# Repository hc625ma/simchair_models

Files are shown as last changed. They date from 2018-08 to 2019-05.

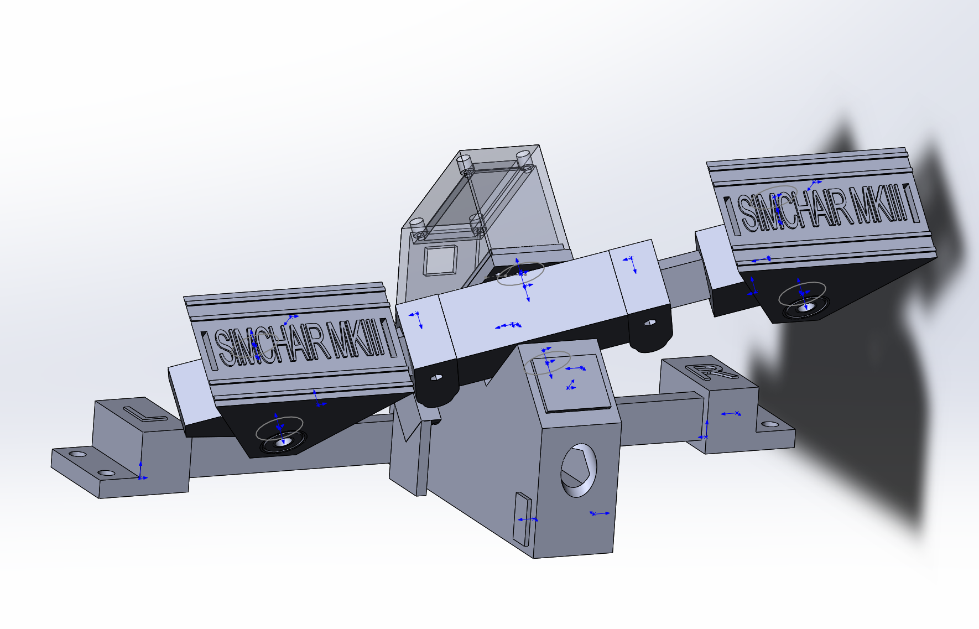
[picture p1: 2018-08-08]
Components/Peripherals/Helicopter pedals/PNG/pedals.png

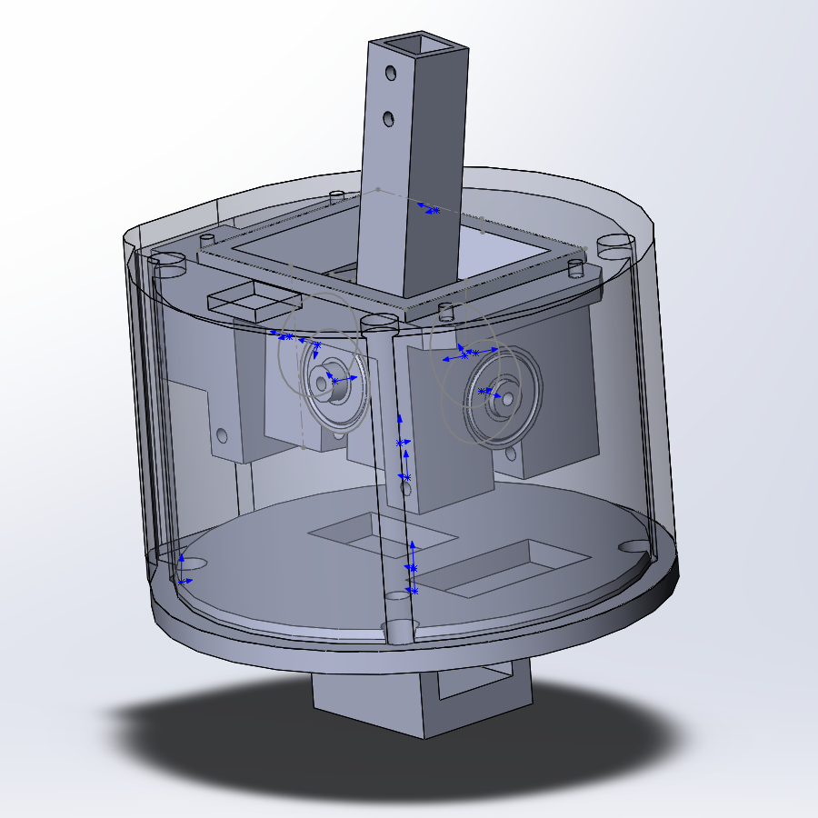
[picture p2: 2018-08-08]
Components/Peripherals/Flight stick gimbal 608zz light/MANUALS/cyclic4.png

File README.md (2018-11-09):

# simchair_models
Simchair MKIII 3D printable models repository

Simchair MKIII

This repo contains all current (supported) models of Simchair MKIII project, sources and oriented STL files. 
All the files are named using this scheme:
peripheral_part_name_partnumber

You can also download all the stuff (and find assembly manuals, BOMs etc) at http://hc625ma.org, the site is auto-synced with models and software repos.

If you have questions, please contact me through comments on the site.

Cheers!

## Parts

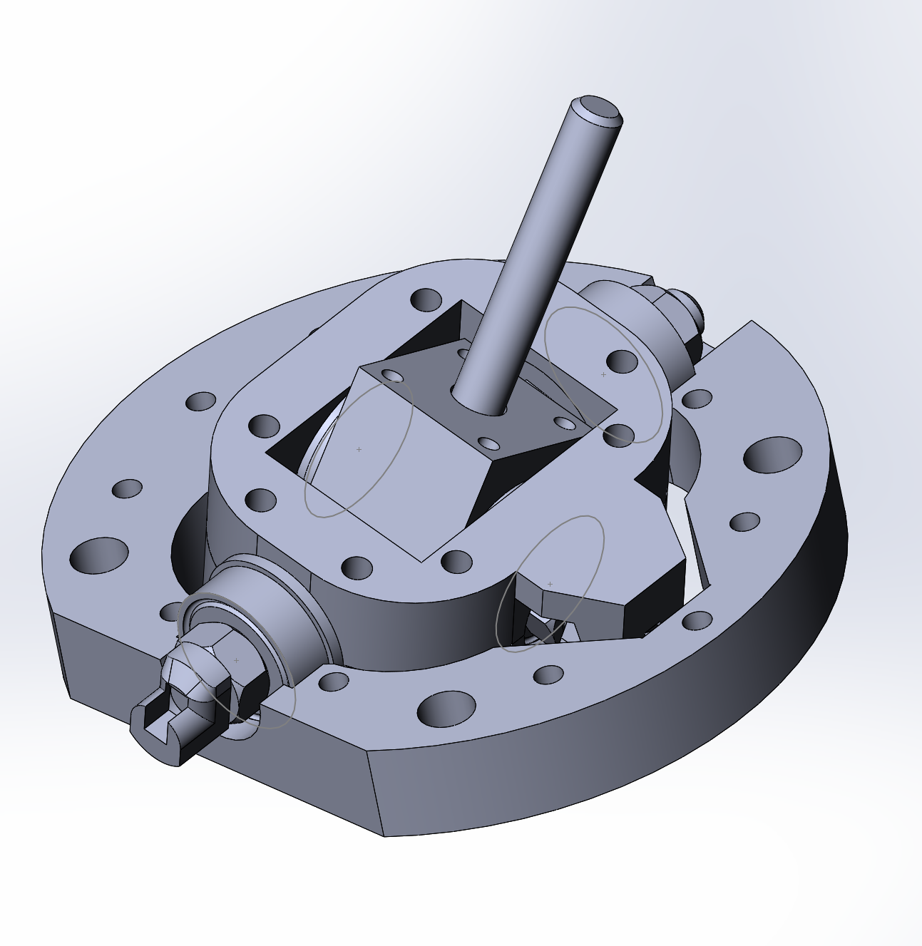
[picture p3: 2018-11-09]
Components/Peripherals/Flight stick gimbal 608zz reinforced/PNG/gimbal06.png

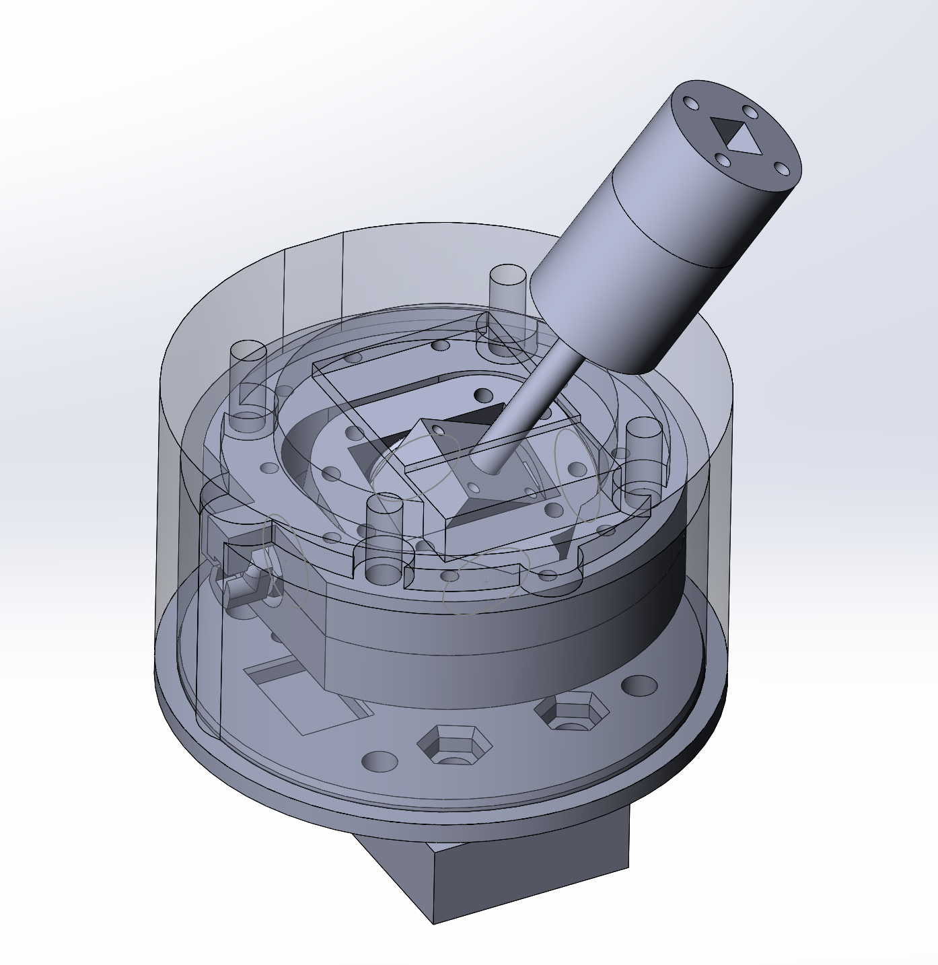
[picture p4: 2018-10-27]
Components/Peripherals/Flight stick gimbal 608zz reinforced/PNG/gimbal01.png

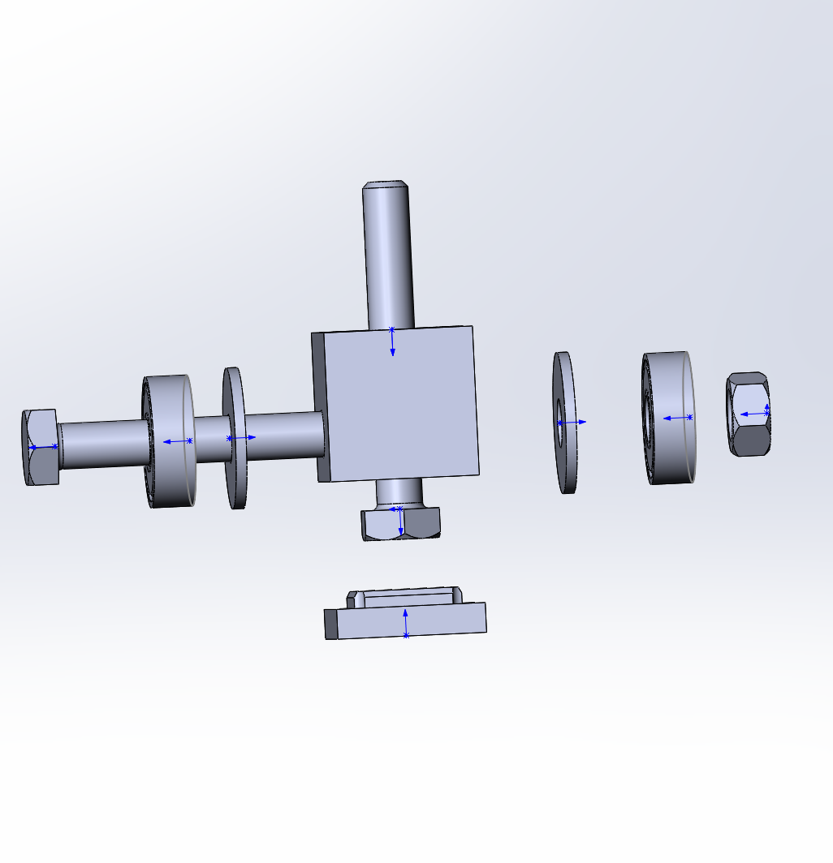
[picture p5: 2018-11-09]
Components/Peripherals/Flight stick gimbal 608zz reinforced/PNG/gimbal02.png

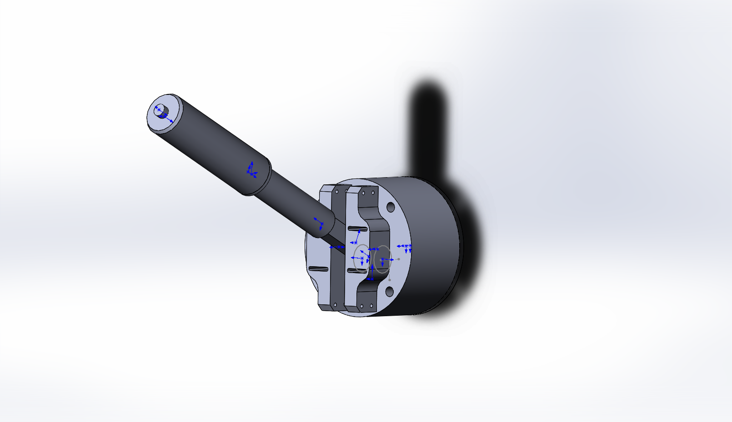
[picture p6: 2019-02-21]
Components/Peripherals/dev/Simple collective/PNG/collective.PNG

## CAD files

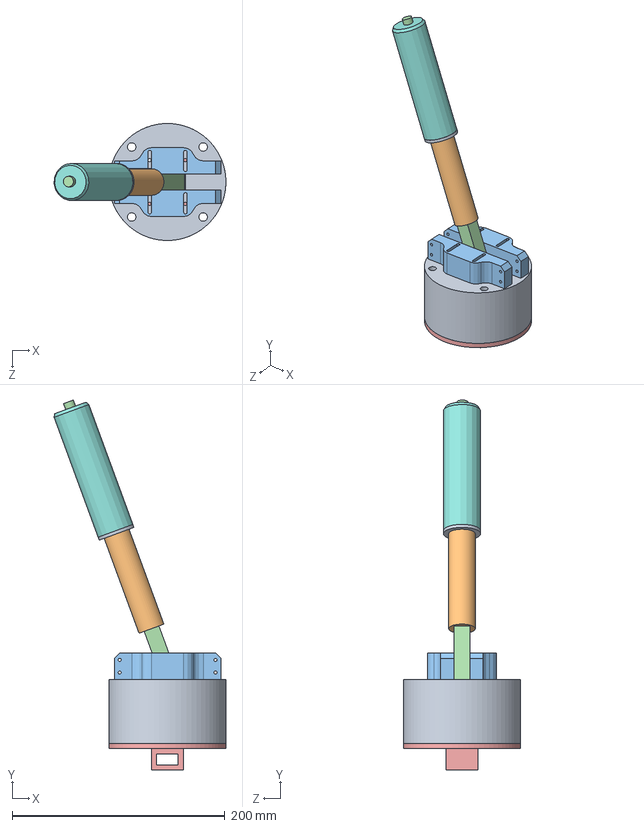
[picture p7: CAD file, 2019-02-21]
Components/Peripherals/dev/Simple collective/SLDPRT/collective.SLDASM
161.5 x 347.7 x 110.0 mm
case_collective
collective_frame_4,5x42mm
608_bearing_v1 x 2
collective_connector
collective_case_bottom_cover
aluminium_square_pipe_10x250
throttle_resistor_mount_v2
throttle
throttle_rear_mount
collective_lever_decorative_cover
tensioner x 2
throttle_handle_wedge

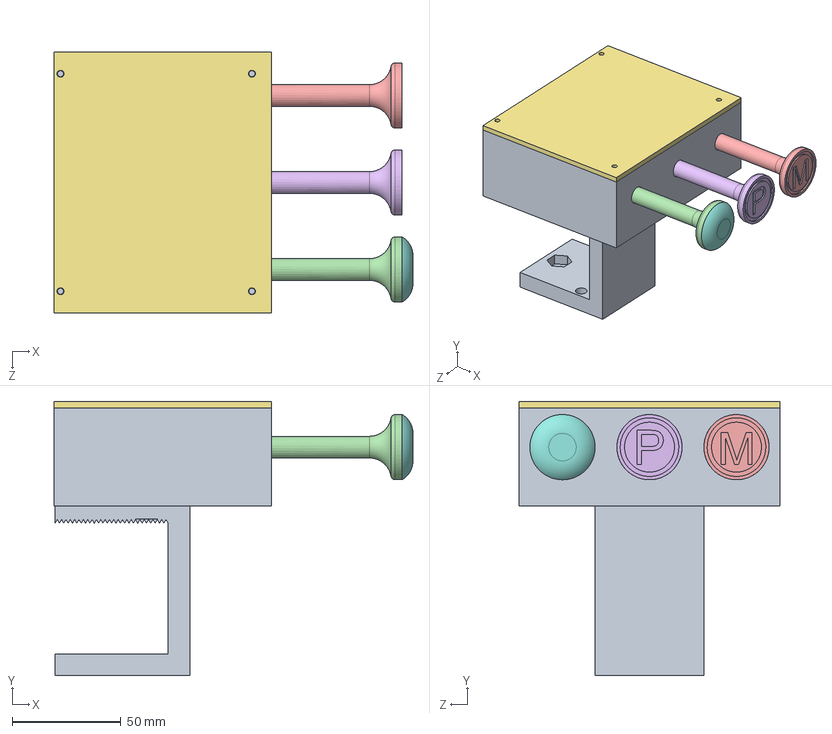
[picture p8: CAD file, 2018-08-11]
Components/Peripherals/Single engine GA controls/SLDPRT/single_eng_ga_controls.SLDASM
165.1 x 126.0 x 120.0 mm
single_eng_ga_controls_enclosure_p1_single_eng_ga_controls01
slider_base x 3
slider x 3
single_eng_ga_controls_throttle_single_eng_ga_controls03
single_eng_ga_controls_mixture_single_eng_ga_controls05
single_eng_ga_controls_prop_single_eng_ga_controls04
single_eng_ga_controls_enclosure_p2_single_eng_ga_controls02
single_eng_ga_controls_knob_cover_single_eng_ga_controls06
single_eng_ga_controls_desk_mount_single_eng_ga_controls07

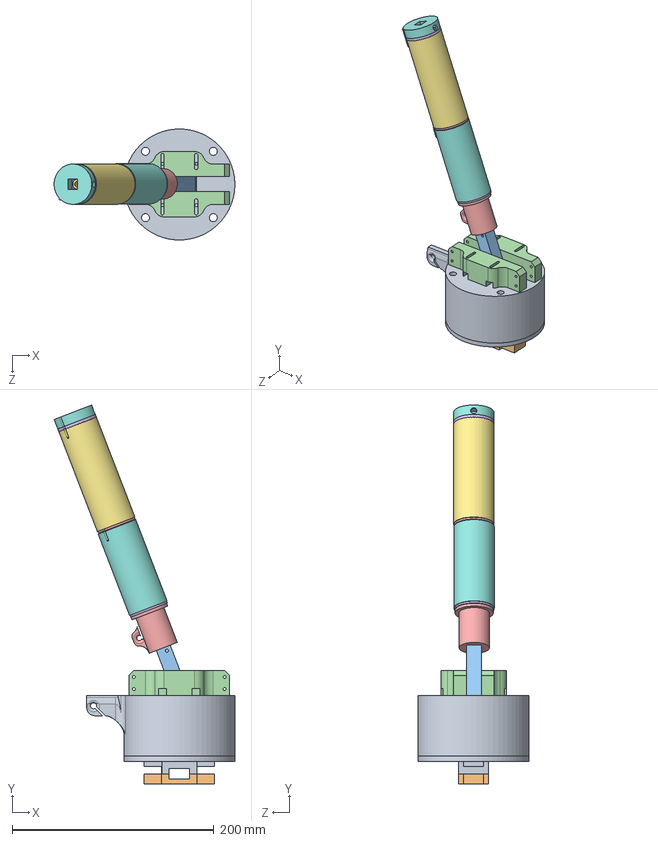
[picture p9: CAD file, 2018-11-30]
Components/Peripherals/Twin collective/SLDPRT/twin_collective.SLDASM
179.1 x 375.5 x 110.0 mm
twin_collective_enclosure_twin_collective01
twin_collective_lever_frame_twin_collective04
608_bearing_v1 x 2
twin_collective_tensioner_twin_collective06 x 2
twin_collective_rubber_bands_holder_twin_collective08
twin_collective_throttle2_frame_p1_twin_collective09
twin_collective_throttle2_frame_p2_twin_collective10
twin_collective_throttle2_grip_twin_collective11
alu_square_pipe_10x10x130
alu_square_pipe_10x10x50
twin_collective_lever_connector_twin_collective05
twin_collective_magnet_holder_6x6x4mm_twin_collective07
twin_collective_throttle1_frame_p1_twin_collective12
twin_collective_throttle1_frame_p2_twin_collective13
twin_collective_throttle1_grip_twin_collective14
twin_collective_head_i2c_connector_housing_twin_collective15
twin_collective_enclosure_bottom_p1_twin_collective02
twin_collective_enclosure_bottom_p2_twin_collective03

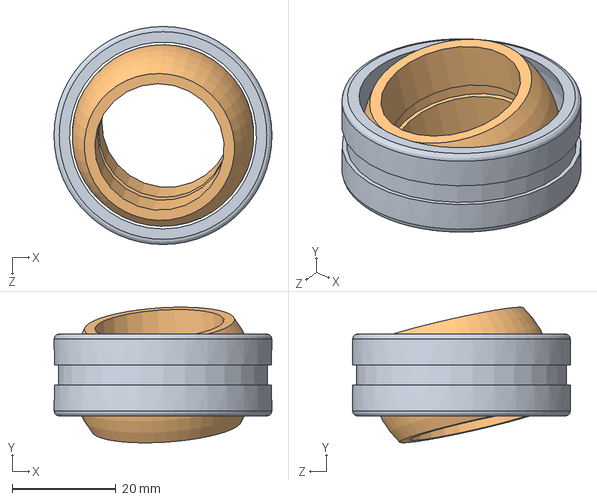
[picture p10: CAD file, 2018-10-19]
Hardware Models/GE25 ES-2RS/GE25 ES-2RS.SLDASM
42.0 x 26.2 x 42.0 mm
outer_ring
inner_ring

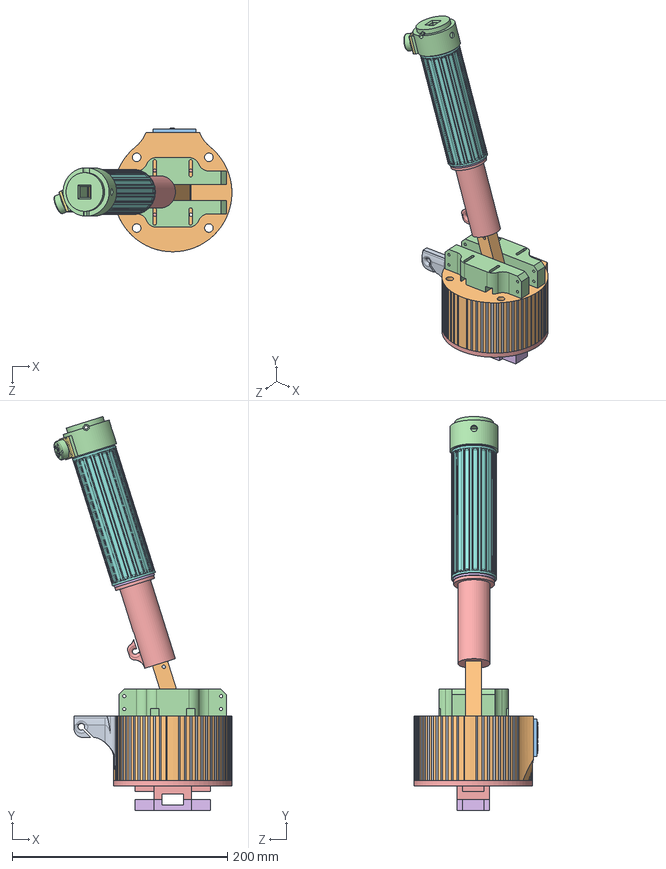
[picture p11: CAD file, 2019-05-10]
Mods/Peripherals/Collective levers/Single engine collective/Mi-8 style throttle grip for physical throttle latch mod/SLDPRT/assembly/single_collective.SLDASM
165.4 x 366.3 x 115.0 mm
single_collective_lever_frame_single_collective04
608_bearing_v1 x 2
single_collective_tensioner_single_collective06 x 2
single_collective_rubber_bands_holder_single_collective08
single_collective_throttle_frame_p1_single_collective09
single_collective_throttle_frame_p2_single_collective10
single_collective_throttle_grip_single_collective11
printable_square_connector_10x177
single_collective_lever_connector_single_collective05
single_collective_magnet_holder_6x6x4mm_single_collective07
single_collective_head_i2c_connector_housing_single_collective12
single_collective_enclosure_bottom_p1_twin_collective02
single_collective_enclosure_bottom_p2_twin_collective03
single_collective_head_i2c_connector_housing_with_detent_p2_single_collective12
single_collective_idle_stop_button_p1_single_collective14
single_collective_idle_stop_button_p2_single_collective15
pneumatic_mod_gimbal_housing_with_revision_hatch_pneumatic_mod14a
pneumatic_mod_gimbal_housing_with_revision_hatch_part_2_pneumatic_mod14b
single_collective_idle_stop_button_p3_single_collective16

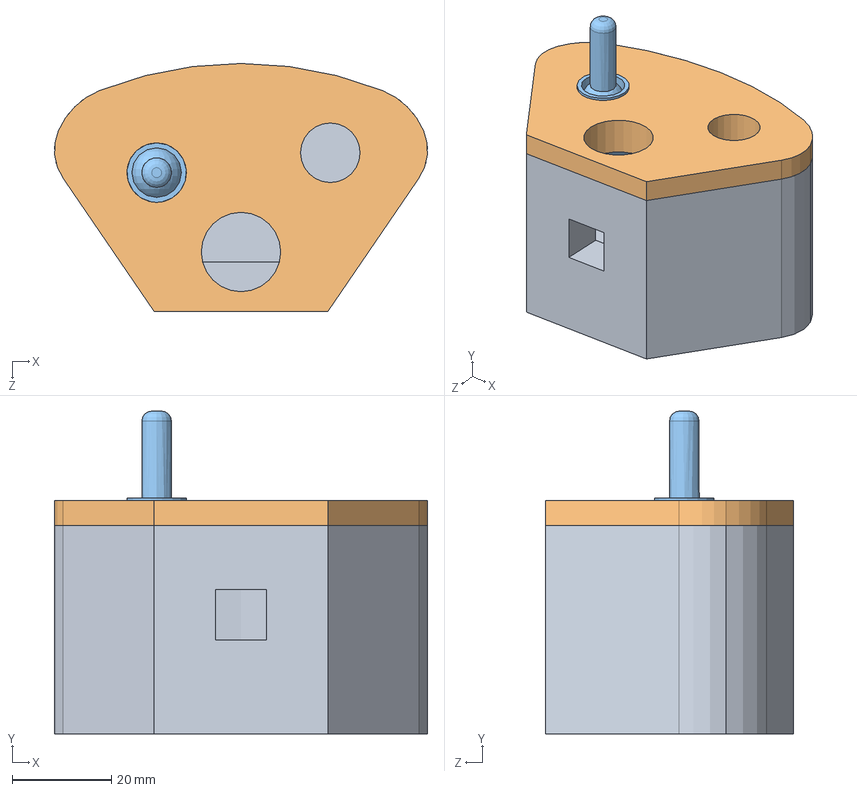
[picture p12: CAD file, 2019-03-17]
Components/Peripherals/dev/B206 collective head/SLDPRT/b206_head.SLDASM
75.2 x 65.1 x 50.0 mm
b206_head_enclosure_p1_b206_head01
b206_head_enclosure_p2_b206_head02
KN3(B)-103A-A3

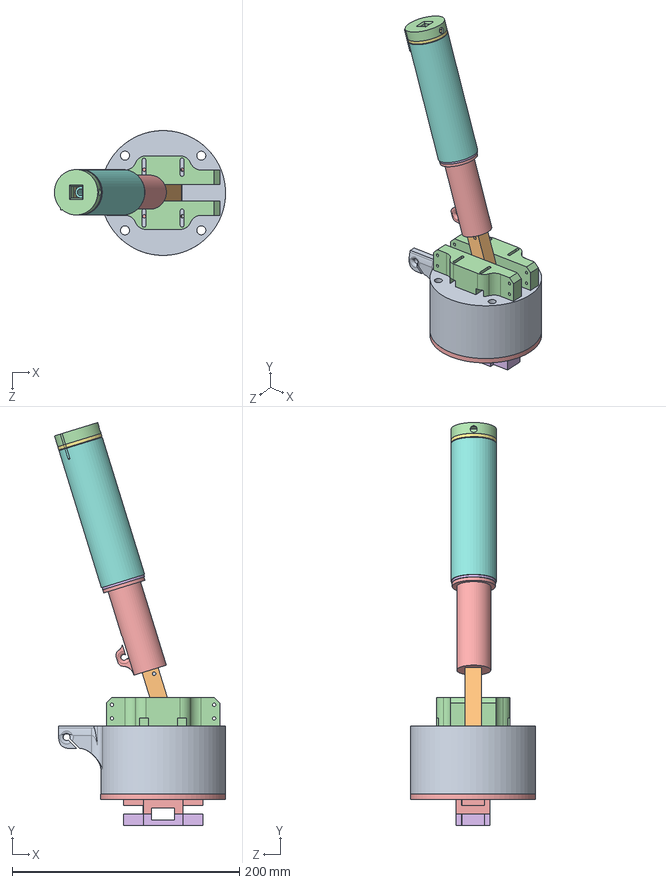
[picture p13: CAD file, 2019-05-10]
Components/Peripherals/Single collective/SLDPRT/single_collective.SLDASM
150.7 x 354.9 x 110.0 mm
single_collective_enclosure_single_collective01
single_collective_lever_frame_single_collective04
608_bearing_v1 x 2
single_collective_tensioner_single_collective06 x 2
single_collective_rubber_bands_holder_single_collective08
single_collective_throttle_frame_p1_single_collective09
single_collective_throttle_frame_p2_single_collective10
single_collective_throttle_grip_single_collective11
printable_square_connector_10x177
single_collective_lever_connector_single_collective05
single_collective_magnet_holder_6x6x4mm_single_collective07
single_collective_head_i2c_connector_housing_single_collective12
single_collective_enclosure_bottom_p1_twin_collective02
single_collective_enclosure_bottom_p2_twin_collective03

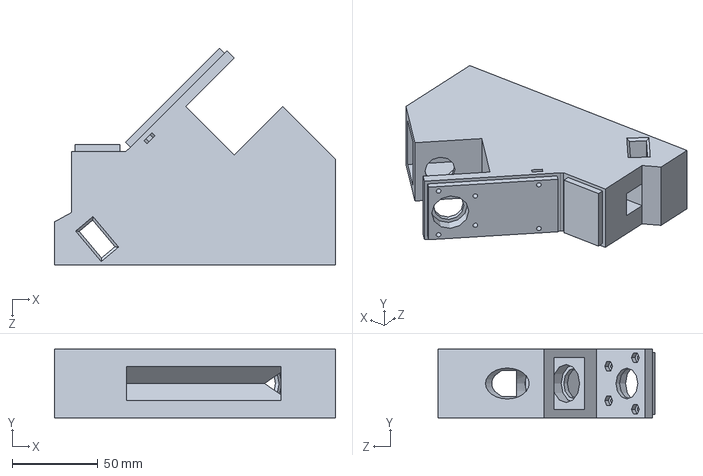
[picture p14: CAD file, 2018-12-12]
Mods/Peripherals/Helicopter pedals/SLDPRT/pedals_main_frame_springs_only_pedals01a.SLDPRT
163.6 x 40.0 x 126.1 mm

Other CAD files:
Components/Controllers/Simchair MKIII I2C controller/SLDPRT/controller_enclosure_p1_controller01.SLDPRT
Components/Controllers/Simchair MKIII I2C controller/SLDPRT/controller_enclosure_p2_3_sockets_controller02.SLDPRT
Components/Controllers/Simchair MKIII I2C controller/SLDPRT/controller_frame_mount_p1_controller03.SLDPRT
Components/Controllers/Simchair MKIII I2C controller/SLDPRT/controller_frame_mount_p2_controller04.SLDPRT
Components/Controllers/Simchair MKIII I2C controller/STL/controller_enclosure_p1_controller01.STL
Components/Controllers/Simchair MKIII I2C controller/STL/controller_enclosure_p2_3_sockets_controller02.STL
Components/Controllers/Simchair MKIII I2C controller/STL/controller_frame_mount_p1_controller03.STL
Components/Controllers/Simchair MKIII I2C controller/STL/controller_frame_mount_p2_controller04.STL
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

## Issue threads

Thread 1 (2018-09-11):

Do you need 1,000mm of square tubing?

carteras, 2018-09-11:
Hey,

Great project. I was just wondering how much tubing do I need approximately? 1000mm of tubing seems like a lot.

Thanks

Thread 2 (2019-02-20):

Beginner questions!

telemole, 2019-02-20:
So sorry to contact here but couldn't find anywhere else to pose a few questions :

Intro: I can solder, math, and learn software very quickly! I have a long history with flight sims and am building a helicopter simulator - your controls looks amazing.  I want to grab a 3d printer, (something like a Creality 10s or 10s pro?), learn to use it, and try this project! I am in Canada and hope all the parts are available to me otherwise.

Do you think the printer listed above and an eager user can accomplish a good result? Thanks so much for this project !!

hc625ma, 2019-02-21:
Hi! Sure, go ahead =) Nothing too complex there at all, basic soldering and basic electronics skills are required (the latter mainly for operating the printer!). Building the set is a fun experience, and you'll love a printer, it's a whole new world of possibilities for a hobbyist. I use p3steel that is much cheaper than Creality, so the latter would be more than enough to handle the print =)

The only part that you won't be able to find locally with ease is probably a Lada clutch spring lol! You can use similar ones or I can mail these to you =)

Please feel free to ask any questions in comments at http://hc625ma.org =)

Cheers!

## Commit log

2018-08-08 test commit
    Test change to binary files
    [gimbal.SLDASM, gimbal_enclosure_gimbal01.SLDPRT]
2018-08-08 Legacy flight stick gimbal lid added
    [608_bearing_v1.SLDPRT, gimbal.SLDASM, gimbal_X_frame_gimbal05.SLDPRT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]
2018-08-08 5x5 magnet holder mod added
    [magnet_holder_5x5mm_socket.SLDPRT, magnet_holder_5x5mm_socket.STL, magnet_holder_5x5mm_socket_offset.SLDPRT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]
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2018-08-09 Helicopter pedals added
    Major pedals improvement! Redesigned Hall effect sensor and magnet mounts. This simplifies calibration a lot, and adds a LOT of precision! Pedals feel perfect now!
    [pedals.SLDASM, pedals_magnet_holder_pedals12.SLDPRT, pedals_magnet_holder_pedals12.STL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]
2018-08-09 10x20mm appertures size adjustments
    [pedals_main_frame_pedals01.SLDPRT, pedals_main_frame_pedals01.STL]
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2018-08-10 pedals main frame alu pipe appertures inclination changed to 40%
    It will be easier to print and press fit the pipe in appertures this way.
    [aluminium_rectangular_pipe_10x20x100mm.SLDPRT, aluminium_rectangular_pipe_10x20x120mm.SLDPRT, gimbal_enclosure_bottom_p2_gimbal03.STL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]
2018-08-11 All current sources added
    This repo now contains all the newest sources. Will be adding STL's with the next commit! Stay tuned!
    [608_bearing_v1.SLDPRT, KN3(B)-103A-A3.SLDPRT, KN3(B)-223A-A3.SLDPRT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]
2018-08-11 The whole project oriented STL's added!
    This repo is now completely populated!
    [ab412_head_enclosure_p1_1_rotary_pot_ab412_head01a.STL, ab412_head_enclosure_p1_2_rotary_pots_ab412_head01b.STL, ab412_head_enclosure_p1_2_rotary_pots_mode_swi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]
2018-08-12 adjusted pedals frame to use less supports
    [pedals.SLDASM, pedals_main_frame_pedals01.SLDPRT, pedals_main_frame_pedals01.STL]
2018-08-12 legacy cyclic gimbal bottom lid name corrected
    [gimbal.SLDASM, gimbal_enclosure_bottom_legacy_p2_gimbal03a.SLDPRT, gimbal_enclosure_bottom_legacy_p2_gimbal03a.STL]
2018-08-13 corrected pedals legs size so they will protect an ethernet cable when pedals are placed against the wall
    [pedals.SLDASM, pedals_frame_front_leg_left_pedals09.SLDPRT, pedals_frame_front_leg_left_pedals09.STL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]
2018-08-13 electronics housing rear nut sockets height adjusted
    [pedals.SLDASM, pedals_main_frame_pedals01.SLDPRT, pedals_main_frame_pedals01.STL]
2018-08-24 some fixes for AB412 head and the twin collective
    Throttle 1 frame part 2 design improved to make tension of throttle grips equal;
    fixed the left pot orientation for AB412 twin rotary pot mods.
    [ab412_head_enclosure_p1_2_rotary_pots_ab412_head01b.SLDPRT, ab412_head_enclosure_p1_2_rotary_pots_ab412_head01b.STL, ab412_head_enclosure_p1_2_rotary_pots_mode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]
2018-08-29 huey head starter trigger reinforcement
    Huey head starter switch reinforcement;
    nut sockets size increased for controller enclosure and B8 stick
    [b8stick.SLDASM, b8stick_left_half_b8stick02.STL, controller.SLDASM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]
2018-08-29 cyclic frame part name error fixed
    [gunde_cyclic_frame_stick_grip_connector_gunde_cyclic_frame04.SLDPRT, gunde_cyclic_frame_stick_grip_connector_gunde_cyclic_frame04.STL]
2018-09-01 minor clearance adjustments
    [ab412_head.SLDASM, ab412_head_enclosure_p1_1_rotary_pot_ab412_head01a.SLDPRT, ab412_head_enclosure_p1_1_rotary_pot_ab412_head01a.STL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]
2018-09-20 pedals frame built-in support structure improvement
    [b8stick_left_half_b8stick02.STL, pedals.SLDASM, pedals_main_frame_pedals01.SLDPRT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]
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2018-09-26 single collective throttle frame part 2 updated
    Copied the throttle frame part 2 design from twin collective lever.
    [pedals.SLDASM, single_collective.SLDASM, single_collective_throttle_frame_p2_single_collective10.SLDPRT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]
2018-09-30 single collective i2c connector housing improved for a better fit.
    [single_collective_head_i2c_connector_housing_single_collective12.SLDPRT, single_collective_head_i2c_connector_housing_single_collective12.STL]
2018-10-11 pneumatic mod released!
    I am releasing the pneumatic mod, that includes MAL-16-150 pneumatic actuator support, a counterweight and rubber bands removal. Please use carefully, especially if you don't own a printer, something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
    [608_bearing_v1.SLDPRT, KN3(B)-223A-A3.SLDPRT, MAL16-150-CA.SLDASM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]
2018-10-19 collective lever mounts for a generic chair with vertical round legs added
    [608_bearing_v1.SLDPRT, 6x4.8mm cylindrical magnet.SLDPRT, 6x6x4mm_magnet_holder.SLDPRT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]
2018-10-19 generic chair mount fix
    [generic_chair_frame_collective_mount_back_generic_chair03.SLDPRT, generic_chair_frame_collective_mount_back_generic_chair03.STL]
2018-10-22 strengthened gimbal released!
    608zz and SS495A sensor based reinforced gimbal is here to test! Also added som dev files for other gimbal variants under dev dir.
    [12x3mm_magnet_holder.SLDPRT, 608_bearing_v1.SLDPRT, 6x6x4mm_magnet_holder.SLDPRT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]
2018-10-23 collective pneumatic mod counteweight housing p2 design improved
    [aluminium_rectangular_pipe_10x20x300mm.SLDPRT, pneumatic_mod_counterweight_housing_p1_pneumatic_mod11.SLDPRT, pneumatic_mod_counterweight_housing_p1_pneumatic_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]
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2018-10-25 throttle quadrant IKEA GUNDE frame mount added
    [ikea_gunde_frame_throttle_quadrant_frame_mount_p1_ikea_gunde_frame07.SLDPRT, ikea_gunde_frame_throttle_quadrant_frame_mount_p1_ikea_gunde_frame07.STL, ikea_gun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]
2018-10-25 STL orientation fix
    [throttle_quadrant_axis_module_throttle_quadrant01.STL]
2018-10-26 5x5x5 magnet holder added for reinforced gimbal
    [gimbal_5x5x5mm_magnet_holder_gimbal12a.SLDPRT, gimbal_5x5x5mm_magnet_holder_gimbal12a.STL, gimbal_5x5x5mm_magnet_holder_incr_tolerance_gimbal12b.SLDPRT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]
2018-10-27 5x5x5 magnet holders clearance adjusted
    [gimbal_5x5x5mm_magnet_holder_gimbal12a.SLDPRT, gimbal_5x5x5mm_magnet_holder_gimbal12a.STL, gimbal_5x5x5mm_magnet_holder_incr_tolerance_gimbal12b.SLDPRT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]
2018-11-09 reingorced gimbal spring holder added
    [MAL16-50-CA.SLDASM, cylinder_body.SLDPRT, cylinder_piston.SLDPRT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]
2018-11-26 Added rubber bands holder replacement part for twin collective lever pneumatic mod
    [pneumatic_mod_twin_lever_decorative_cover_pneumatic_mod15a.SLDPRT, pneumatic_mod_twin_lever_decorative_cover_pneumatic_mod15a.STL]
2018-11-30 added new adjustable cyclic stick frame
    [gimbal_reinforced.SLDASM, gimbal_stick_connector_nut_gimbal13.SLDPRT, gimbal_stick_connector_nut_gimbal13.STL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]
2018-12-09 a space for wires added to the reinforced gimbal bottom lid
    [gimbal_housing_lid_p1_gimbal02.SLDPRT, gimbal_housing_lid_p1_gimbal02.STL, gimbal_reinforced.SLDASM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]
2018-12-12 pedals main frame imroved to avoid cracks when press-fitting 300mm alu tubing
    [pedals.SLDASM, pedals_main_frame_pedals01.SLDPRT, pedals_main_frame_pedals01.STL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]
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2018-12-16 5x5x5mm magnet magnet holder mod added for pedals
    [pedals_magnet_holder_5x5x5mm_pedals12a.SLDPRT, pedals_magnet_holder_5x5x5mm_pedals12a.STL]
2018-12-16 5x5x5mm magnet holder mod for pedals STL orientation fix
    [pedals_magnet_holder_5x5x5mm_pedals12a.STL]
2018-12-24 important changes to the reinforced flight stick gimbal and stick frame
    fixed tolerances, replaced spring holders to adjustable ones, fixed holders are moved to "mods" section and are generally not recommended to use; stick frame has been redesigned to avoid turning of its parts under load.
    [gimbal_adjustable_spring_holder_gimbal14.SLDPRT, gimbal_adjustable_spring_holder_gimbal14.STL, gimbal_reinforced.SLDASM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]
2019-01-04 Pneumatic mod lever connector lower ring 3mm screw holes diameter adjusted
    [gimbal_stick_connector_p3_gimbal10.STL, pneumatic_mod_lever_connector_ring_p1_pneumatic_mod09.SLDPRT, pneumatic_mod_lever_connector_ring_p1_pneumatic_mod09.STL]
2019-02-06 important updates for the reinforced flight stick gimbal
    a better housing for the gimbal, featuring the revision hatch for an easy access to Y axis magnet holder was added;
    gimbal rings assembly can now be extracter without the need to remove an ethernet socket;
    spring holder support ring increases precision noticeably;
    FTCR button added
    [608_bearing_v1.SLDPRT, fctr_button_housing.SLDASM, gimbal_5x5x5mm_magnet_holder_incr_clearance_gimbal12b.SLDPRT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]
2019-02-06 reingorced gimbal minor fixes for Y axis hatch cover
    [gimbal_Y_sensor_hatch_cover_gimbal15.SLDPRT, gimbal_Y_sensor_hatch_cover_gimbal15.STL, gimbal_Y_sensor_hatch_cover_gimbal20.SLDPRT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]
2019-02-06 IKEA GUNDE frame parts with increased clearance added
    0,4mm clearance for easier fit
    [ikea_gunde_0,4mm_chair_back_mount_malinda_plate.stl, ikea_gunde_0,4mm_frame_collective_frame_mount_left_150_deg_ikea_gunde_frame02a.STL, ikea_gunde_0,4mm_frame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]
2019-02-10 Test version of an improved IKEA MALINDA pillow back mod for an IKEA GUNDE chair added
    [ikea_gunde_frame_0.4mm_ikea_malinda_chair_back_mount_v2_ikea_gunde_frame_06b.SLDPRT, ikea_gunde_frame_0.4mm_ikea_malinda_chair_back_mount_v2_ikea_gunde_frame_0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]
2019-02-21 pneumatic mod gimbal housing with a revision hatch added
    [608_bearing_v1.SLDPRT, aluminium_square_pipe_10x250.SLDPRT, case_collective.SLDPRT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]
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2019-03-01 new "scale" Bell 412 head top panel added
    [ab412_head_enclosure_p2_print_ab412_head02a.SLDPRT, ab412_head_enclosure_p2_print_ab412_head02a.STL]
2019-03-17 B206 and VRMAX collective heads added to dev section
    [KN3(B)-103A-A3.SLDPRT, MTS-101-A2.SLDPRT, MTS-223-A2.SLDPRT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]
2019-03-19 vrmax colelctive head dev fixes
    [ab412_head_enclosure_p1_radio_panel_ready_ab412_head01d.STL, ab412_head_radio_panel_housing_p1_ab412_head_radio_panel01.SLDPRT, ab412_head_radio_panel_housing_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]
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2019-04-12 fixes for physical idle release button mod and left pedal holder
    [ab412_head_enclosure_front_cover_p2_radio_panel_ready_ab412_head06.SLDPRT, ab412_head_enclosure_front_cover_p2_radio_panel_ready_ab412_head06.STL, ab412_head_e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]
2019-05-10 single collective hotfix + reinforced gimbal v2 sketch
    [608_bearing_v1.SLDPRT, M8 washer.SLDPRT, bolt_M8_30mm.SLDPRT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]
2019-05-31 Huey-style 30-degree inclined collectie mount for IKEA GUNDE added
    [40mm_profile_bracket.SLDASM, 40mm_profile_bracket_p1.SLDPRT, 40mm_profile_bracket_p1.STL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]
2019-06-21 socketed version of the collective rear lid for pneumatic mod
    [M6 nut.SLDPRT, M6x30mm.SLDPRT, M6x35mm.SLDPRT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]
